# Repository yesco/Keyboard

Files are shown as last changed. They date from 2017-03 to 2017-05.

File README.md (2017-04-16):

# Keyboard

Aspiration is to lasercut a functional keyboard with functional electrical switches.

The current experimential ideas:
- lasercut keys with hinges that bounces and make keys movable
- have foamy stuff below
- make electrical connection of wire/paths by a kind of xy-grid
- decode by simple circuit, output serial ascii? esp8266 coprocessor

## Cutting

- wood: 2.7mm playwood speed:30 power:55
- plexiglas: according to wiki

## Problems

Sometimes some shapes makes problem.

- Inkscape: Path-ObjectToPath, Extensions-ModifyPath-FlattenBezier 0.1
- Cutter: Select All, make one color, some colors make problem
- The characters seems to make it take forever to "prepare", delete them?

# Box

## Problems

- OpenSCAD doesn't choose unit, edit SVG file exported add "mm" at top tag
- Use svg, don't export to dxf as it's not good (?)
- Make sure bottom board doesn't cut off peg
  (object union, change to no fill)
- Then export to DXF

## lizzie

that's a thing

- when you import the image into inkscape, you need to go to document properties in inkscape and change the units to mm, and "1 user unit per mm" (edited)
- then when you save it as a dxf, you need to select "px" as the unit to export it as
- i have no clue why but it gets me things the size I expect.

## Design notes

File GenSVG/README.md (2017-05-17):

http://www.instructables.com/id/PCB-designing-and-isolationmilling-only-using-free/

command line incscape

https://secure.ssa.gov/OSSS/eb/eb001View.do

Dec Hex    Dec Hex    Dec Hex  Dec Hex  Dec Hex  Dec Hex   Dec Hex   Dec Hex  

  0 00 NUL  16 10 DLE  32 20    48 30 0  64 40 @  80 50 P   96 60 `  112 70 p
  1 01 SOH  17 11 DC1  33 21 !  49 31 1  65 41 A  81 51 Q   97 61 a  113 71 q
  2 02 STX  18 12 DC2  34 22 "  50 32 2  66 42 B  82 52 R   98 62 b  114 72 r
  3 03 ETX  19 13 DC3  35 23 #  51 33 3  67 43 C  83 53 S   99 63 c  115 73 s
  4 04 EOT  20 14 DC4  36 24 $  52 34 4  68 44 D  84 54 T  100 64 d  116 74 t
  5 05 ENQ  21 15 NAK  37 25 %  53 35 5  69 45 E  85 55 U  101 65 e  117 75 u
  6 06 ACK  22 16 SYN  38 26 &  54 36 6  70 46 F  86 56 V  102 66 f  118 76 v
  7 07 BEL  23 17 ETB  39 27 '  55 37 7  71 47 G  87 57 W  103 67 g  119 77 w
  8 08 BS   24 18 CAN  40 28 (  56 38 8  72 48 H  88 58 X  104 68 h  120 78 x
  9 09 HT   25 19 EM   41 29 )  57 39 9  73 49 I  89 59 Y  105 69 i  121 79 y
 10 0A LF   26 1A SUB  42 2A *  58 3A :  74 4A J  90 5A Z  106 6A j  122 7A z
 11 0B VT   27 1B ESC  43 2B +  59 3B ;  75 4B K  91 5B [  107 6B k  123 7B {
 12 0C FF   28 1C FS   44 2C ,  60 3C <  76 4C L  92 5C \  108 6C l  124 7C |
 13 0D CR   29 1D GS   45 2D -  61 3D =  77 4D M  93 5D ]  109 6D m  125 7D }
 14 0E SO   30 1E RS   46 2E .  62 3E >  78 4E N  94 5E ^  110 6E n  126 7E ~
 15 0F SI   31 1F US   47 2F /  63 3F ?  79 4F O  95 5F _  111 6F o  127 7F DEL

American Layout/Swedish Layout

A: ~!@#$%^&*()_+
A: `1234567890-=
S: 1/2 !"#$%&/()=?`
S: par 1234567890+'

A: QWERTYUIOP{}|
A: qwertyuiop[]\
S: QWERTYUIOPA^
S: qwertyuiopPA~

A: ASDFGHJKL:"
A: asdfghjkl;'
S: ASDFGHJKLOA
S: asdfghjkloa

A: ZXCVBNM<>?
A: zxcvbnm,./

** TODO: consider using hzeller postscript generation: 

https://github.com/hzeller/ldgraphy/blob/master/hardware/laser-cut-case.ps

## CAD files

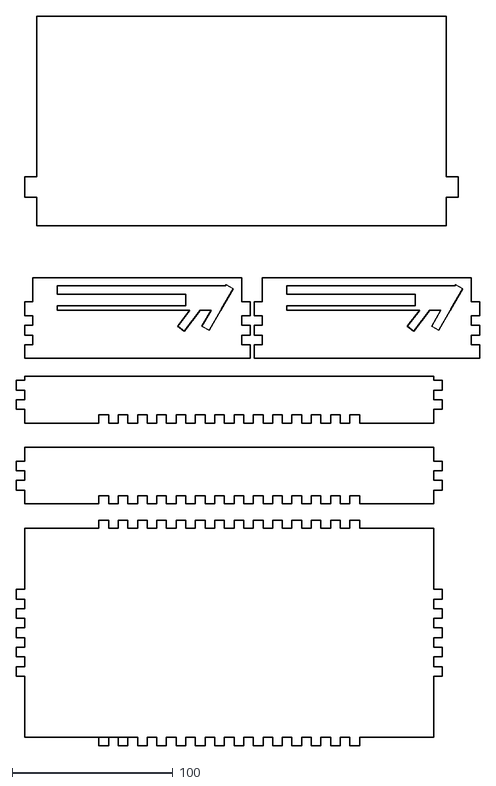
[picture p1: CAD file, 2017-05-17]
box-002_slide.dxf
287.9 x 453.2

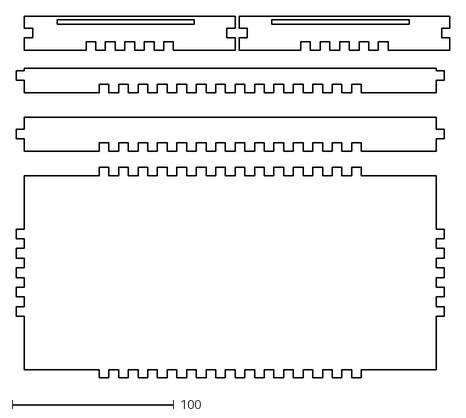
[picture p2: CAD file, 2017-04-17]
box-001.dxf
267.9 x 223.7

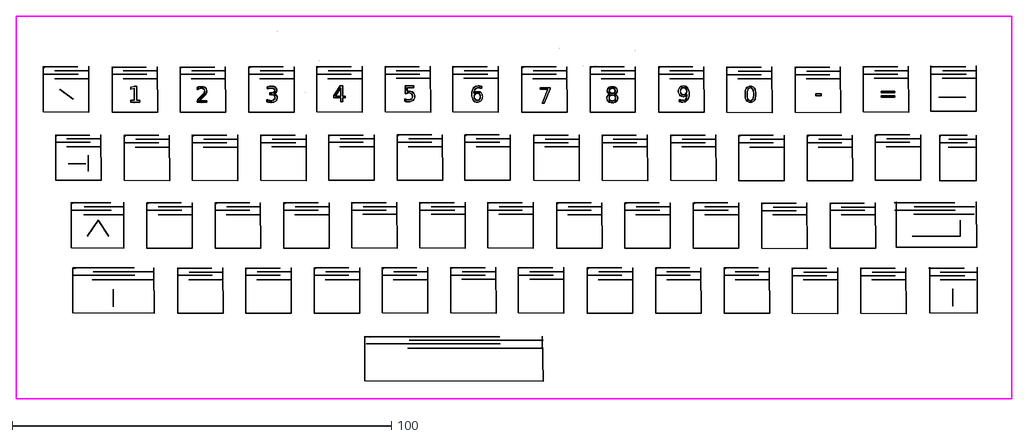
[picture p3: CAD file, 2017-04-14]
keyboard-005_0-9.dxf
262.4 x 100.8

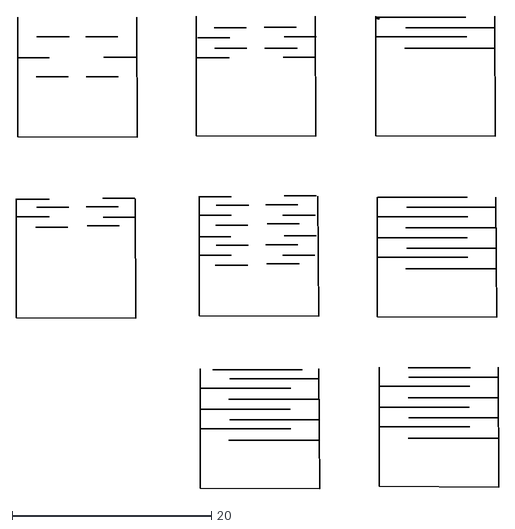
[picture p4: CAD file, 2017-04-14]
key-003.dxf
48.4 x 47.4

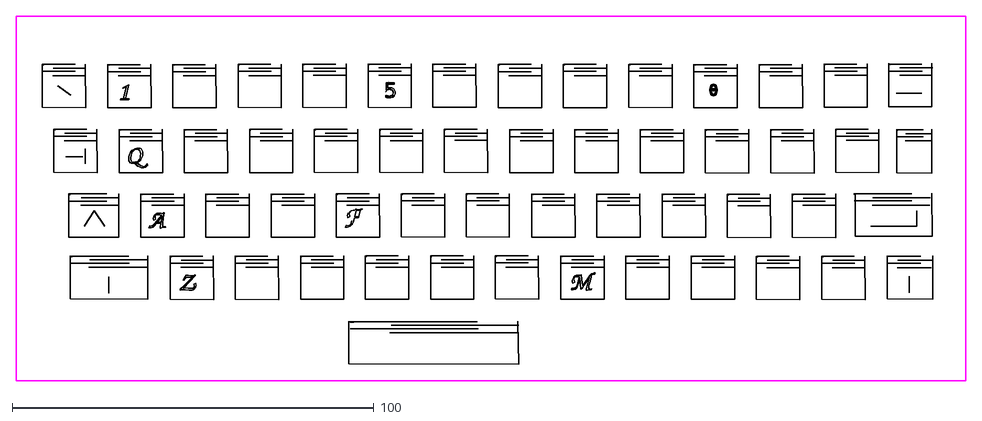
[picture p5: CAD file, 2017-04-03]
keyboard-003_space_ctrl_shift.dxf
262.4 x 100.8

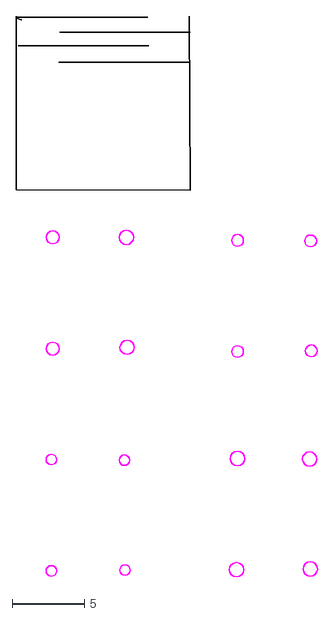
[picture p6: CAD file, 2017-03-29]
key-circuit.dxf
20.8 x 38.7

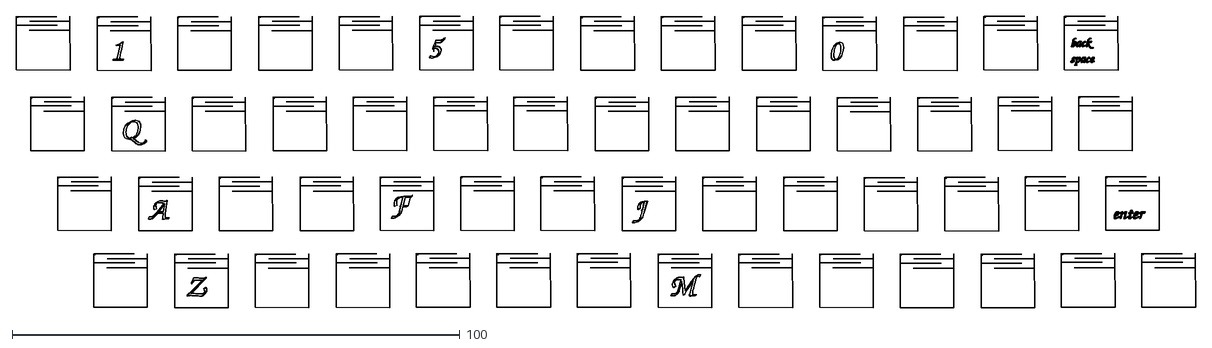
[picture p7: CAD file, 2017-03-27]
keyboard-001.dxf
263.3 x 65.2

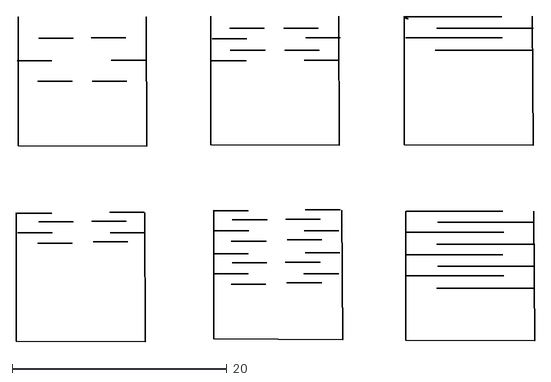
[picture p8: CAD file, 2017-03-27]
key-002.dxf
48.2 x 30.3

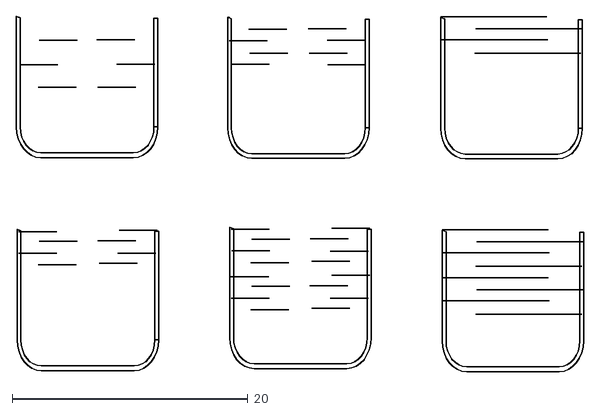
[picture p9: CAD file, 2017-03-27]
key-001.dxf
48.1 x 30.2

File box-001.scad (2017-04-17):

// constants

thickness = 5.07; // material thickness
kbdthick = 2.8;

height = 120;
length = 260-2*kbdthick;
depth = 16+thickness;

// rail stuff
side_margin = 7.5;
hole_offset = 3.0;
hole_diam = 3.2;


rail_depth = 6;
rail_tongues = 12;

//rail = 2 * hole_offset;
rail = 2 * hole_offset;

module around_box (height, width) {
    for (i=[0:$children-1]) {
        rotate([0, 0, -90 * i]) {
            translate([i == 1 ? -width : 0 + i == 2 ? -height : 0,
                       i == 2 ? -width : 0 + i == 3 ? -height : 0]) {
                children(i);
            }
        }
    }
}

module tongues(length, count, fitting, thickness) {
    margin = (length - (fitting * (2 * count - 1))) / 2;
    for (i=[0:count-1]) {
        translate([0, margin + i * 2 * fitting]) {
            square([thickness, fitting]);
        }
    }
}

module tongues_in(length, count, fitting, thickness) {
    if (count < 0) {
        tongues(length, - count, fitting, thickness);
    }
}

module tongues_out(length, count, fitting, thickness) {
    if (count > 0) {
        translate([-thickness, 0]) {
            tongues(length, count, fitting, thickness);
        }
    }
}

module puzzle (width, height, fitting, counts) {
    difference () {
        union () {
            square([width, height]);
            around_box(width, height) {
                tongues_out(height, counts[0], fitting, thickness);
                tongues_out(width, counts[1], fitting, thickness);
                tongues_out(height, counts[2], fitting, thickness);
                tongues_out(width, counts[3], fitting, thickness);
            }
        }
        around_box(width, height) {
                tongues_in(height, counts[0], fitting, thickness);
                tongues_in(width, counts[1], fitting, thickness);
                tongues_in(height, counts[2], fitting, thickness);
                tongues_in(width, counts[3], fitting, thickness);
        }
    }
}

module nothing() { square(0); }

module rect(width, heigth) { square([thickness, fitting]); }

module side(width, height, fitting, counts) {
  // This punches hole for the rail
//  difference() {
    puzzle(width, height, fitting, counts);
//    translate([0, -10]) {
//      around_box(width, height) {
//        nothing();
//        translate([0, 10]) {
//          square([2.64,100]);
//        //        tongues_out(width, rail_tongues, fitting, thickness);
//        }
//        nothing();
//        nothing();
//      }
//    }
//  }
}

module kbd_hole(depth) {
  translate([thickness*4, depth-thickness*1])
  color("red")
  square([100-3*thickness, 2.64]);
}

module unit(length, depth) {
   // bottom
   puzzle(length, height, rail, [5, 14, 5, 14]);

   // long sides
   translate([0, height + thickness*2 + 5]) {
     side(length, depth, rail, [1, 0, 1, -14]);

     translate([0, depth + thickness*2 + 5]) {
           difference() {
             side(length, depth, rail, [1, 0, 1, -14]);
             translate([0, depth-thickness*1.2])
               color("red")
                 square([length, thickness*2]);
           }

         // short sides
         translate([0, depth + thickness*2 - 5]) {
             difference() {
               puzzle(height + thickness*2, depth, rail, [-1, 0, -1, -5], rail);
               kbd_hole(depth);
             }

             translate([height + thickness * 2.5, 0]) {
                 difference() {
                   puzzle(height + thickness*2, depth, rail, [-1, 0, -1, -5], rail);
                   kbd_hole(depth);
                 }
             }
         }
      }
   }
}

unit(length, depth);

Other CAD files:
keyboard-004_space_ctrl_shift-no-letters.dxf
box-002_slide.scad
box-lizzie.scad

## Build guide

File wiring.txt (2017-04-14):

Seems one can wire many things with 2 diods, in cascade:
any 2 high, 3 high, 4 highs

          2 3 4 5 6 7 
        ------------- 
       0:   0 @ P ` p                   16 ---
       1: ! 1 A Q a q            1      16 --1
       2: " 2 B R b r           2-      16 -2-
       3: # 3 C S c s           21      16 (21)
       4: $ 4 D T d t          4--      16 4--
       5: % 5 E U e u          4-1      16 (41)
       6: & 6 F V f v          42-      16 (42)
       7: ' 7 G W g w         (6)1      16 (7)
       8: ( 8 H X h x         8---      16 8--
       9: ) 9 I Y i y         8--1      16 (9)
       A: * : J Z j z         8-2-      16 (10)
       B: + ; K [ k {         8-(3)     16 (11)
       C: , < L \ l |         84--      16 (12)
       D: - = M ] m }         8(5)      16 (12)
       E: . > N ^ n ~         8(6)      16 (12)
       F: / ? O _ o DEL       8(7)      16 (12)

`~	1!	2@	3#	4$
xx	[N1]	[N2]	[N12]	[N4]

tab	q	w	e	r
xx	[H1]	[H7]	[L5]	[H2]
		h6

ctrl	a	s	d	f
xx	[L1]	[H3]	[L4]	[L6]

shift	z	x	c	v
xx	[HA]    [H8]	[L3]	[H6]

			shift			ctrl
N => 3 = -21		=>   = -2-
L => 6 = 42-            => 4 = 4--		---
H => 7 = 421		=> 5 = 4-1		--1

ctrl sets bit 4 to 0 for letters
letter sets bit 4 (unless ctrl)

shift sets bit 2 to 0 for letters
shift sets bit 1 to 0 for numbers

bit 2:
  1 for normal letters
  0 for shift letters
  1 for numbers

bit 1:
  1 for numbers (and some symbols)
  0 for symbols shifted

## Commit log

2017-03-27 version 2, 1 didn't work
    [key-002.dxf]
2017-03-27 add keyboard proto, no space etc, just some keys to feel it out.
    [keyboard-001.dxf]
2017-03-29 try cut holes for laser micro switches
    [key-circuit.dxf]
2017-04-03 add wiring data
2017-04-03 added modified keyboard
    [keyboard-003_space_ctrl_shift.dxf]
2017-04-03 box cut
    [keyboard-003_space_ctrl_shift.dxf]
2017-04-14 experiment with more stable key, two fasting pads of different size.
    [key-003.dxf]
2017-04-14 add numbers
    [keyboard-004_space_ctrl_shift-no-letters.dxf, keyboard-005_0-9.dxf]
2017-04-15 make a simple box, based on lizzie-box!
    [box-001.scad, box-lizzie.scad]
2017-04-15 change thickness to 5.07mm
    [box-001.dxf, box-001.scad]
2017-04-15 changed size of keyboard, moved it forward, moved teeth around of sides
    [box-001.dxf, box-001.scad]
2017-04-15 various changes for the keyboard - undo messedup knobs - make smaller box - lower front
    [box-001.dxf, box-001.scad]
2017-04-15 instructions for openscad
    [box-001.dxf]
2017-04-16 edit dxf instead, get unit right
    [box-001.dxf]
2017-04-16 fix pegs size
    [box-001.dxf, box-001.scad]
2017-05-09 changed colors add text to keys frame shift offset
2017-05-17 new keys and sliding box
    [box-002_slide.dxf, box-002_slide.scad]
2017-05-17 move nob on lid
    [box-002_slide.dxf, box-002_slide.scad]
2017-05-17 adjust for thicker lid, only two slots, better fit...
    [box-002_slide.dxf, box-002_slide.scad]
